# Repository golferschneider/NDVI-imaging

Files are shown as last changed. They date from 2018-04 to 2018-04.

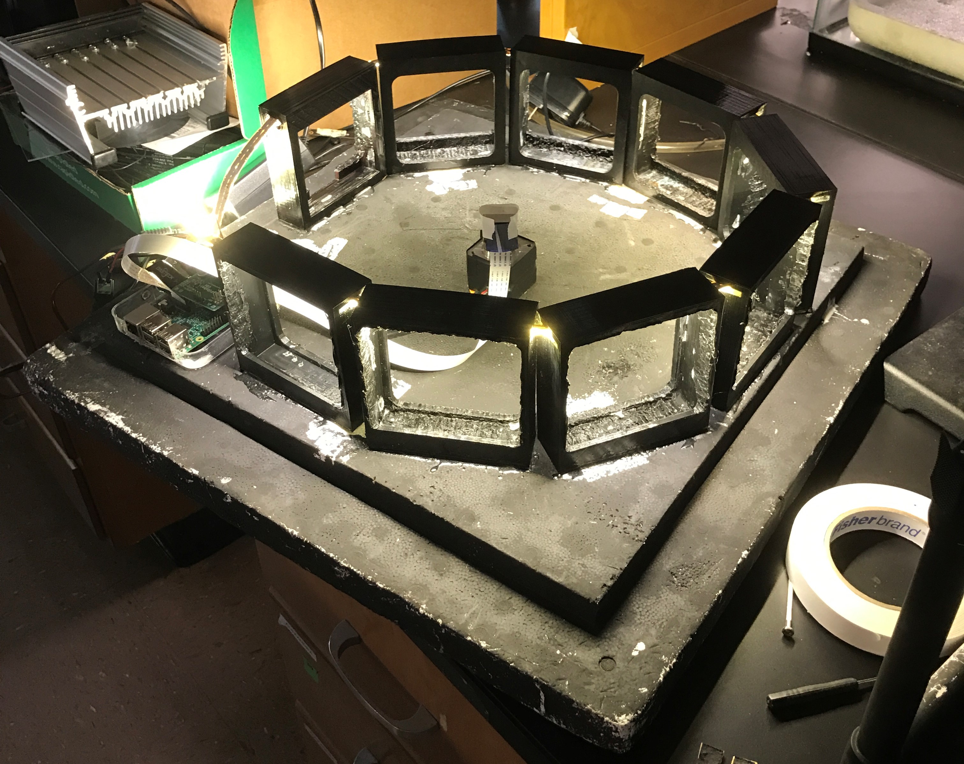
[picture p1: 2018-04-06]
Image and .sld files of imaging device/Phase 2.jpg

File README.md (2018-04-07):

# NDVI-imaging
For raspberry pi to power Led light strip, usb camera and stepper motor.
DISCLAMER: this was my first python project so please have mercy on me!

Hardware: 
  - Raspberry pi 2 B
  - RasPiRobot v3 board for controlling the stepper motor
  - I beleive we used a Nema 23 stepper motor
  - Rosco #2007 filter/gel (to put over camera)

*runImaging.py*  
  This controls the lights, stepper motor, and sets up all directories to hold the image files. 
  -> This makes a call to "takePicture.py"
 
 *takePicture.py*  
   Takes picture and does all NDVI computations saving a greyScale and the falseColor to the directory sent into the takePic method.
   Current problem: the naming convention when saving images might not be optimal, not intuitive to tell when the image was taken by 
        looking at image name.
   
*generateTimeLapse.py*  
  Creates a time lapse image of all the images in a folder. Creates a cool video to show the growth or deterioration of a plant!

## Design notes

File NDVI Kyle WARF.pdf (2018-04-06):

Fig 3. These images are from rotational NDVI imaging system.

Normalized Difference Vegetative Index (NDVI) imaging allows one to see plant photosynthesis activity. Stress induces changes in photosynthesis and so it is possible deduce if a plant is stressed in real time using this approach. This type of imaging is possible because photo-synthetically active plants absorb blue wavelengths but reflect near infra-red (NIR) light.

To get the values needed in the NDVI equation we need to use an RGB sensor camera with a blue filter which lets us obtain both the blue and NIR areas in the spectrum in the blue and red channels. There are many different products currently on the market, but unfortunately these products are very expensive and have to be manually operated.

# Progressive plant health monitoring: NDVI

# Kyle Schneider¹,3, Richard Barker

1

# , Amit Nimunkar

2

# , Simon Gilroy

1

## 1) Gilroy Astro-Botany Lab, University of Wisconsin—Madison 2) Engineering department, University of Wisconsin—Madison 3) Industrial engineering, University of Wisconsin—Madison

# Introduction

# Methods

# Results

3

# Discussion

# References

## Acknowledgement

1

I’d like to thank NASA and NSF for funding.

Drs Barker, Nimunkar and Gilroy for guidance

Adam Steinberg for poster advice and template

A webcam had the infra-red (IR) exclusion filter replaced with a blue/NIR filter. This was then mounted on a
stepper motor. The camera
was then surrounded by 6
PVC ‘halos’ containing strips of variable RGB and warm
white LED’s. The whole
system is then controlled by Python codes run on a
raspberry pi microcomputer.

From making a time lapse of the false color images its easy to see how plant health changes over time. Another advantage of using time-lapse of the images in conjunction with the six petri dish holding capacity is that it is easy to compare a healthy plant with a plant that is, for example infected with pathogen. This gives us insight into how long it takes the plant to stop photosynthesis, and also where in the plant it stops photosynthesis first.

Original
IR picture

Greyscale
NDVI

False color

Original image is run through code which subtracts the blue channel, which due to the filter only allows blue visible light to be recorded. NIR is simultaneously captured in the red channel.

To get from NDVI to false color one looks at the range of grey scale values and then converts the different tones of gray into certain colors determined by a pseudo-color look up table.

## Image processing

## Image acquisition

2

Our goal is to make an automated system that takes NDVI pictures of plants creating time-lapse video of plant stress response. Additionally we are using a design built around an inexpensive IR camera. The product we have made can hold six petri dishes of plant seedlings. Being able to compare these six different time lapse videos would allow us to non-invasively detect what part of the plant shuts down photosynthesis in response to a range of stresses.

# Future work

1

st day post infection 2

nd day of infection 3

rd day of infection

Public Lab provided python codes: https://publiclab.org/wiki/infragram International Maize and wheat center: http://www.plantstress.com/methods/Greenseeker.PDF

This series of images demonstrates that this cost effect method of observing photosynthetic capacity is capable of detecting signs of pathogen-induced stress before any physiological signs of harm can be observed using normal imaging.
3

rd day of infection

## Preliminary Conclusion

- We aim to test the changes in plant photosynthetic responses to flooding, drought, salt, heat, cold, mechanical stimulation, cosmic radiation, increased G-forces and micro-gravity.
- We then hypothesize that certain genes may reduce the negative impact of these environmental factors and will investigate this hypothesis by testing mutant plants or transgenic over expression lines.

4

This technology can easily be implemented into drones which could be used to regularly assess plant health in fields. The drone could then automatically relay the data it acquires regarding plant health to the farmers. If the computer measures any decline in photosynthesis in a certain region it would alert a human who can see what the problem is and address it. The key thing about this approach to NDVI technology using a relatively cheap camera (<$50) is that it accessible to everyone, from gardeners to commercial agriculture.

5

## Time Lapse of Images

## Application in precision agriculture

Scatter corrected reflectance

Wavelength (nm)

This equation is applied in every pixel of an image to make a grey scale normalized image which is then rendered into a false color scale so it is easier to see the relative levels of photosynthesis.

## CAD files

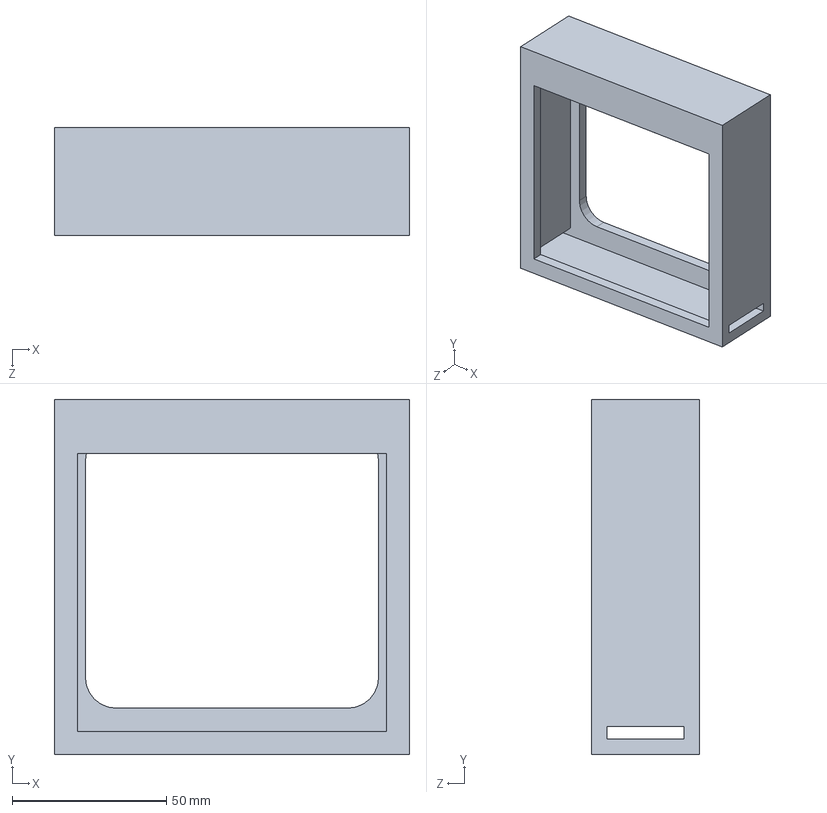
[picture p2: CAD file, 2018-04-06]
Image and .sld files of imaging device/square petri dish holder.SLDPRT
115.0 x 115.0 x 35.0 mm

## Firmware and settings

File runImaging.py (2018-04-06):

"""
*************************************************************************
* Created for: Gilroy Lab @ UW-Madison
* Created by: Kyle Schneider on Jan 23rd, 2016
* _______________________
*
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
"""


import RPi.GPIO as GPIO
### for stepper motor board
from rrb3 import *
import time
import sys
### for LEDs
import pigpio
### for taking pictures
import subprocess
import os
import takePicture
#import testWebCam

GenColor = True
GenGrey = True

#The number of false colors must be equal to (N*4)+1
#for instance, (2*4)+1 = 9
# or (64*4)+1 = 257
numFalseColors = 1025
#setting up LEDs
pi = pigpio.pi()
# strip 1 of lights
RED_PIN1 = 17
GREEN_PIN1 = 22
BLUE_PIN1 = 24
# strip 2 of lights
RED_PIN2 = 25
GREEN_PIN2 = 13
BLUE_PIN2 = 18
# strip 3 of lights
RED_PIN3 = 27
GREEN_PIN3 = 04
BLUE_PIN3 = 20

#setting motor voltage and input voltage
rr = RRB3(12.0,12.0)

#initalize it to -1 so we know if anything is wrong
petriDishes = -1;

def setLights(pin, brightness):
    pi.set_PWM_dutycycle(pin, brightness)

#This gives the program information on how many directories to set up for images to store in
def askDishes():
    petriDishes = input("How many petri dishes did you put in? ")

    if petriDishes > 6:
        print "must be between 1-6"
        askDishes()

    if petriDishes < 1:
        print "must be between 1-6"
        askDishes()

    print petriDishes
    return petriDishes
    
#makes directories
def mkdir_p(path):
    try:
        os.makedirs(path)
    except OSError as exc:
        if exc.errno == errno.EEXIST and os.path.isdir(path):
            pass
        else:
            raise

def find_dir():
    print ('finding dir')
    directory = os.getcwd()
    print directory

#makes a folder system for your new project inside of directory the program was called from
def settingUpFolders():
    global testName
    testName = raw_input("your test name(no spaces allowed)? ")
    mkdir_p(os.getcwd() + '/' + testName)
    print ('folder ' + testName + ' has been created')

    global petriDishes
    petriDishes = askDishes()

    for x in range(0,petriDishes):
        if x == 0:
            num = 'One'
        if x == 1:
            num = 'Two'
        if x == 2:
            num = 'Three'
        if x == 3:
            num = 'Four'
        if x == 4:
            num = 'Five'
        if x == 5:
            num = 'Six'
        mkdir_p(os.getcwd() + '/' + testName + '/dish' + num)
        mkdir_p(os.getcwd() + '/' + testName + '/dish' + num + '/regPic')
        mkdir_p(os.getcwd() + '/' + testName + '/dish' + num + '/greyScale')
        mkdir_p(os.getcwd() + '/' + testName + '/dish' + num + '/NDVI')


def main():
	print "Please enter petri dishes in order from 1-6,"
	print "also please make sure the camera is pointed at "
	print "petri dish one before starting."	

	settingUpFolders()
	timeInMin = input("How many minutes would you like inbetween each picture? ")

	try:
	    while True:
    	    delay = 10
    	    stepsFor = 8
        	stepsBack = 8 * (petriDishes-1)
        
        	# set 3 testing
        	setLights(RED_PIN3, 255)
        	setLights(BLUE_PIN3, 255)
        	setLights(GREEN_PIN3, 0)
        	    
        	for x in range(0,petriDishes-1):            
            	if x == 0:
                	dishNum = 'One'
            	if x == 1:
                	dishNum = 'Two'
            	if x == 2:
                	dishNum = 'Three'
            	if x == 3:
            	    dishNum = 'Four'
            	if x == 4:
            	    dishNum = 'Five'
            	if x == 5:
            	    dishNum = 'Six'
           
           		takePicture.takePic(os.getcwd() + "/" + testName + "/dish" + dishNum)
            	###other ways to take pictures...
            	#testWebCam.takePic(os.getcwd() + "/" + testName + "/dish" + dishNum) 
            	#subprocess.Popen([sys.executable, "takePicture.py", str(dishNum)])
            	###### end camera code #####
            	rr.step_forward(int(delay)/1000.0,int(stepsFor))
            	print 'start timing'
            	time.sleep(60*timeInMin)
            	print 'end timing'
        	#### camera code
        	if petriDishes == 1:
        	    dishNum = 'One'
        	if petriDishes == 2:
        	    dishNum = 'Two'
        	if petriDishes == 3:
        	    dishNum = 'Three'
        	if petriDishes == 4:
        	    dishNum = 'Four'
        	if petriDishes == 5:
        	    dishNum = 'Five'
        	if petriDishes == 6:
        	    dishNum = 'Six'
        	takePicture.takePic(os.getcwd() +"/" + testName + "/dish" + dishNum)
        	###other ways to take pictures...
        	#testWebCam.takePic(os.getcwd() + "/" + testName + "/dish" + dishNum) 
        	#subprocess.call([sys.executable, "takePicture.py", str(dishNum)])
        	rr.step_reverse(int(delay)/1000.0,int(stepsBack))
        	time.sleep(60*timeInMin)
        
	finally:
    	try:
    		setLights(RED_PIN3, 0)
    		setLights(BLUE_PIN3, 0)
    		setLights(GREEN_PIN3, 0)
    	GPIO.cleanup()

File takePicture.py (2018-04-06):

#!/usr/bin/python

# -*- coding: utf 8 -*-

"""
*************************************************************************
* Created for: Gilroy Lab @ UW-Madison
* Created by: Alex Bilgri on Dec 3rd, 2015
* Modified by: Kyle Schneider on Jan 23rd, 2016
* _______________________
*
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
import sys
import os
import datetime
from subprocess import call
from PIL import Image
import picamera
from time import sleep
import time

GenColor = True
GenGrey = True
#The number of false colors must be equal to (N*4)+1
#for instance, (2*4)+1 = 9
# or (64*4)+1 = 257
numFalseColors = 1025

def NDVI(photName, directory):
   """Generates greyscale and false color image as needed"""
   
   
   if GenGrey == True:
       
       print "Opening photo for greyscale generation..."
       #print directory + "/regPic/" + photName + ".jpg"
       startGS = time.clock()
       img = Image.open(directory + "/regPic/" + photName + ".jpg")
       width, height = img.size
       pixels = img.load()
       
       for x in range(0,width):
           #print x
           for y in range(0,height):
               #Store each pixel in a variable
               onePixel = pixels[x,y]

               if ((onePixel[0] and onePixel[2]) == 0):
                   newPixel = 0
               else:
                   #Perform the NDVI transform if red and blue are non-zero
                   ###for blue filter
                   newPixel = ((float(onePixel[0])-float(onePixel[2]))/(float(onePixel[0])+float(onePixel[2])))
                   ###testing for red filter
                   #newPixel = ((float(onePixel[2])-float(onePixel[0]))/(float(onePixel[2])+float(onePixel[0])))
                   #NDVI creates a number between -1 and 1               
                   #Normalized to 0-255
                   newPixel += 1                
                   newPixel *= 127.5

               #The next step only takes integers, round               
               newPixel = int(round(newPixel))
               #print newPixel
               #write each pixel with NDVI
               pixels[x,y] = (newPixel, newPixel, newPixel) #order is (Red, Green, Blue) Derp
       
       #save greyscale
       endGS = time.clock()
       print "Saving photo..."
       print endGS - startGS
       img.save(directory + "/greyScale/" + photName + "greyScale.jpg")
   
   
   if GenColor == True:
       
       #Open File
       print "opening photo for False-color generation..."
       startFC = time.clock()
       img = Image.open(directory + "/regPic/" + photName + ".jpg")
       #img = Image.open(directory + "/regPic/" + photName + ".jpg")
       width, height = img.size
       pixels = img.load()
       
       #generate a 256 color list (0,0,255) to (255,0,0) is blue to red
       colorList = genColorList(numFalseColors)
       for x in range(0,width):
           #print x
           for y in range(0,height):
               #Store each in a variable
               onePixel = pixels[x,y]
               if ((onePixel[0] and onePixel[2]) == 0):
                   newPixel = 0
                   #print "NANA"
               else:
                   #NDVI transform
                   newPixel = ((float(onePixel[0])-float(onePixel[2]))/(float(onePixel[0])+float(onePixel[2])))
                   #adjust -255 to 255
                   newPixel *= numFalseColors-1
                   #print newPixel
                   
               
	       #Round for next step
               newPixel = -int(round(newPixel))
               #Write pixel with the NDVI lookup in colorList
               pixels[x,y] = colorList[newPixel]
               
       #save image!
       endFC = time.clock()
       print "Saving photo..."
       print endFC - startFC
       img.save(directory + "/NDVI/" + photName + "NDVI.jpg")
       print "***********************************************"
  

def genColorList(n):
    """Generates n-long list of tuples that contain RGB values 
       between blue and red"""
       
    #number of transition steps between the below 4 functions
    q = (n-1)/4
    
    colorList = []
    
    #Blue to blue-green (0,0,255) -> (0,255,255)
    for i in range(0,q):
        j = int(255*i/q)
        colorList.append((0,j,255))
      
    #Blue-green to Green (0,255,255) -> (0,255,0)
    for i in range(0,q):
        j = 255-int(255*i/q)
        colorList.append((0,255,j))
        
    #Green to yellow (0,255,0) -> (255,255,0)
    for i in range(0,q):
        j = int(255*i/q)
        colorList.append((j,255,0))
        
    #Yellow to red (255,255,0) -> (255,0,0)
    for i in range(0,q+1):
        j = 255-int(255*i/q)
        colorList.append((255,j,0))
        
        
    return colorList

def genName():
    """account for any zeros in the date, like '06' instead 
    of '6' for 6AM"""
    
    UTC = datetime.datetime.utcnow()
    time = UTC - datetime.timedelta(hours = 6) #correct for CST

    if time.minute > 9:
	    minutes = str(time.minute)
    elif time.minute == 0:
	    minutes = '00'
    else:
	    minutes = '0' + str(time.minute)

    if time.hour > 9:
	    hours = str(time.hour)
    elif time.hour == 0:
	    hours = '00'
    else:
	    hours = '0' + str(time.hour)

    if time.day > 9:
	    days = str(time.day)
    else:
	    days = '0' + str(time.day)

    if time.month > 9:
	    months = str(time.month)
    else:
	    months = '0' + str(time.month)

    ##########needs to be revamped, naming convention is not very good...
    #photoname = "/home/pi/Desktop/" + testName + "/dish" + petriDishNum + "%s" % (time.year) + months + days + hours + minutes + ".jpg"
    photoname = "%s" % (time.year) + months + days + hours + minutes
    print photoname
    return photoname




def takePic(directory):
   photName = genName()
   print directory + "/regPic/" + photName + ".jpg"
   imageName = directory + "/regPic/" + photName + ".jpg"
   takePhotoCmd = "fswebcam --rotate 270 -r 1280x960 -S 30 " + imageName
   call([takePhotoCmd], shell = True)
   NDVI(photName, directory)


####OTHER WAYS FOR TAKING IMAGES WITH PI CAMERA

##takePhotoCmd = "fswebcam -r 1200x900 -S 30 " + photName
##print photName
##takePhotoCmd = photName
##call ([takePhotoCmd], shell = True)

##camera = picamera.PiCamera()
##camera.resolution = (1024, 768)
##camera.vflip = True
##camera.brightness = 50
##camera.capture(photName)

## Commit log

2018-04-06 Images and solidworks files of imaging device
    Helps to put a visual aspect to what the code controlled.
    [Imaging Device.SLDASM, square petri dish holder.SLDPRT]
2018-04-06 Images and .sld files of the imaging device
    [square petri dish holder.SLDPRT]
